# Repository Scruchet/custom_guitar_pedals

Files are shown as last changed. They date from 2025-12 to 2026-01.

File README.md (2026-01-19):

# Custom Guitar Pedals

## Introduction
Since I started learning how to play the electric bass and guitar, and while learning new songs, I discovered effect pedals. They change the sound of the instrument by adding more texture and character. Many different types of pedals exist, and I wanted to understand how they work.

My research is mainly based on a book that I highly recommend: *Electronics for Guitarists* (third edition).

## Project Structure
This repository contains all the files needed to create your own guitar pedals, from electronic design to 3D models and circuit simulation.

The main directory is divided into three subdirectories:
- **mechanical**: Fusion 360 and STEP files for the enclosure
- **pcb**: KiCad projects with an HTML-generated BOM for easier assembly
- **simulation**: LTSpice projects used to design and validate the two main circuits

## Effects
The project currently includes two pedals:
- A clipping pedal
- A fuzz face–style pedal

## Assembly
To assemble the pedals, you will need several components. All passive and active components are listed in the BOM available at `pcb/bom/ibom.html`.

You can 3D print the enclosure, but I do not really recommend it. A pedal needs to be solid and reliable, especially for stage use.  
I bought aluminum enclosures from AliExpress and adapted the designs to fit the available space. The quality is not the best, but this is a DIY project after all.

You will need:
- Two 6.35 mm jack connectors (input and output)
- One DC jack for the power supply
- One LED with its current-limiting resistor
- One 3PDT guitar footswitch

All the components I used are listed in the `components.txt` file.

## Results

`images/result.jpg`

## Project Status

Tested, need pictures for the readme

## License
All hardware designs, schematics, PCB layouts, and mechanical files in this repository
are released under the CERN Open Hardware Licence v2 – Permissive (CERN-OHL-P).

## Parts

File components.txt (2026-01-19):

DC connector : https://fr.aliexpress.com/item/1005010690243937.html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
LED housings : https://fr.aliexpress.com/item/1005010179964783.html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
Pedal Aluminum Box Enclosure : https://fr.aliexpress.com/item/1005006474336072.html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
6.35 mm connectors : https://fr.aliexpress.com/item/1005006144019774.html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
3PDT Guitar Foot Switch : https://fr.aliexpress.com/item/1005009252439906.html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
Potentiometer Knobs : https://fr.aliexpress.com/item/1005009658071171.html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

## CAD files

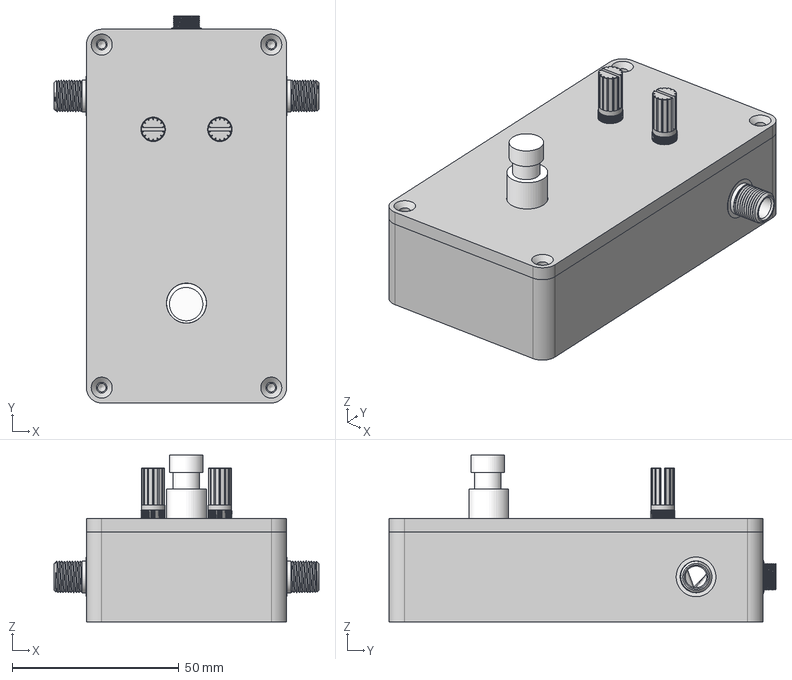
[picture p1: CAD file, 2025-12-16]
mechanical/exports/assembly.step
79.3 x 116.0 x 50.0 mm
PotentiometerB10K x 2
L12B x 2
721A

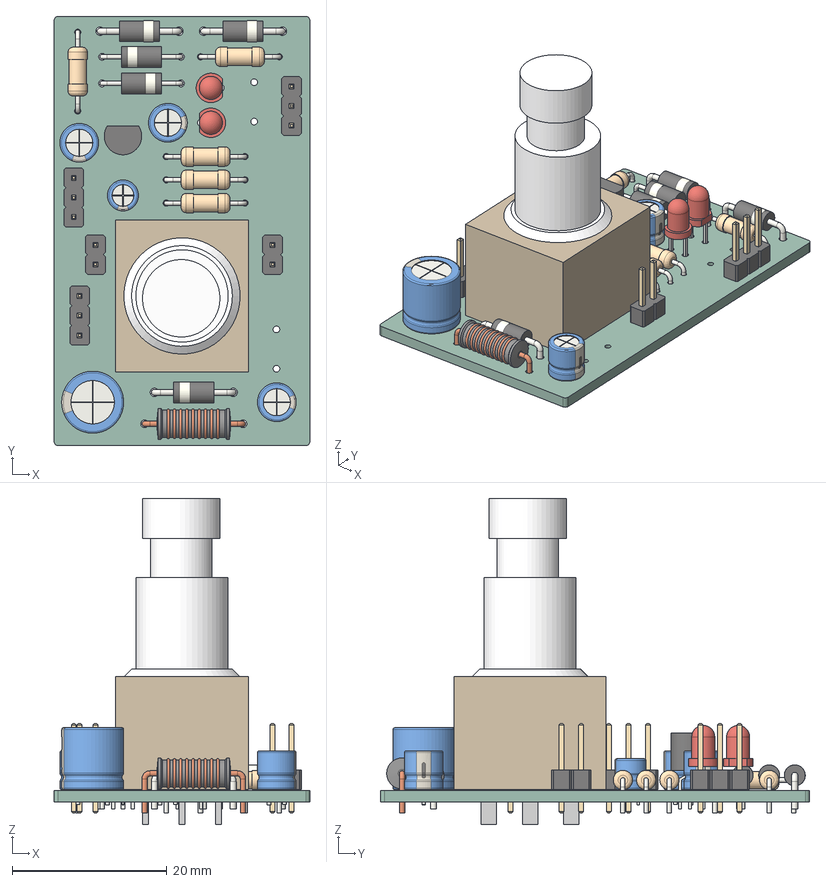
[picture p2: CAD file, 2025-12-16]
mechanical/exports/PCB.step
33.0 x 55.4 x 42.1 mm

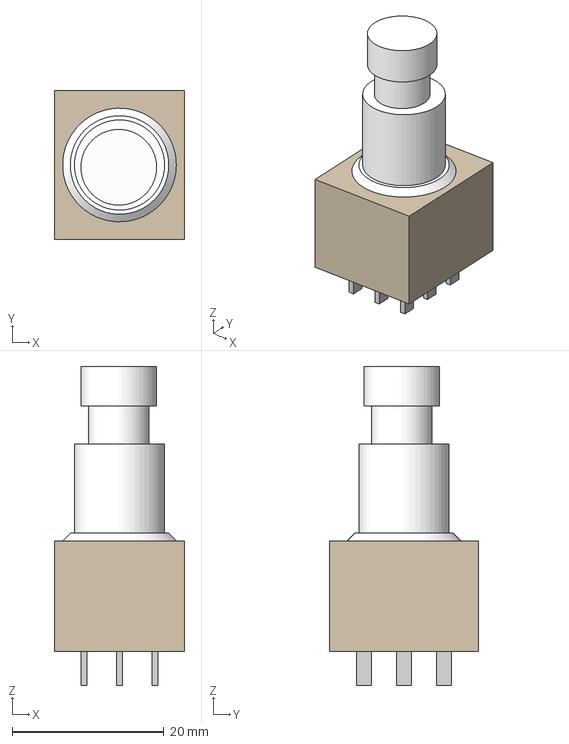
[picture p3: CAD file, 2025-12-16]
pcb/librairies/3d/Switch principal.step
17.2 x 19.6 x 42.1 mm

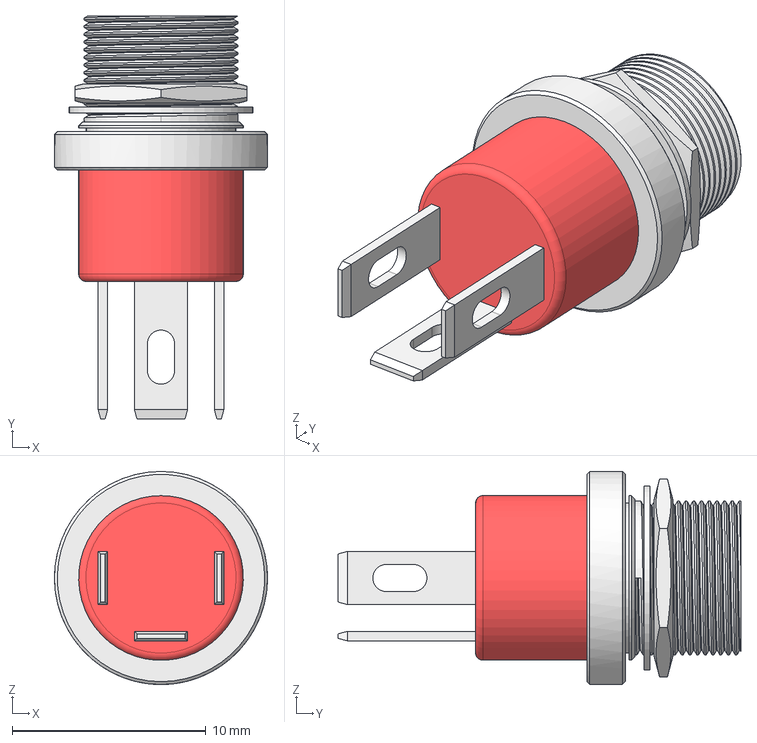
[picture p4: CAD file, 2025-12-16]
mechanical/exports/DC connector.step
11.0 x 20.8 x 11.0 mm

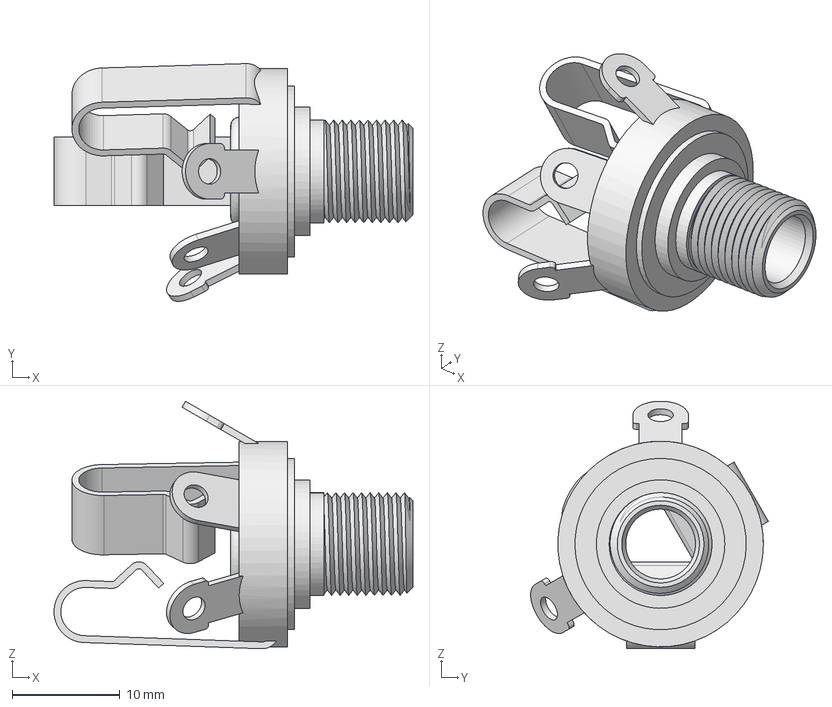
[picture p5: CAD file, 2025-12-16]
mechanical/exports/jack 6.35mm audio.step
33.3 x 22.0 x 22.9 mm

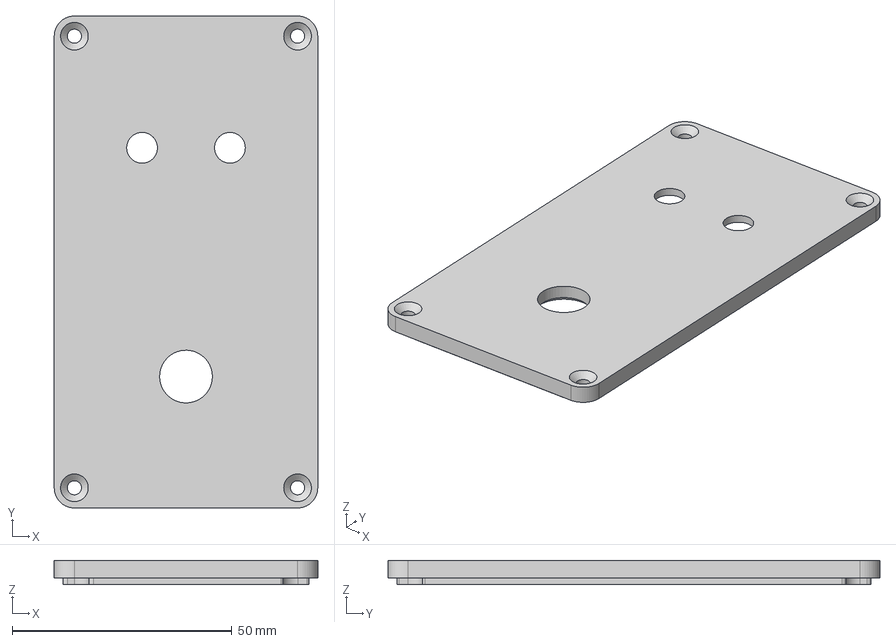
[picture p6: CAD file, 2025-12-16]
mechanical/exports/top_shield.step
60.0 x 112.0 x 5.50 mm

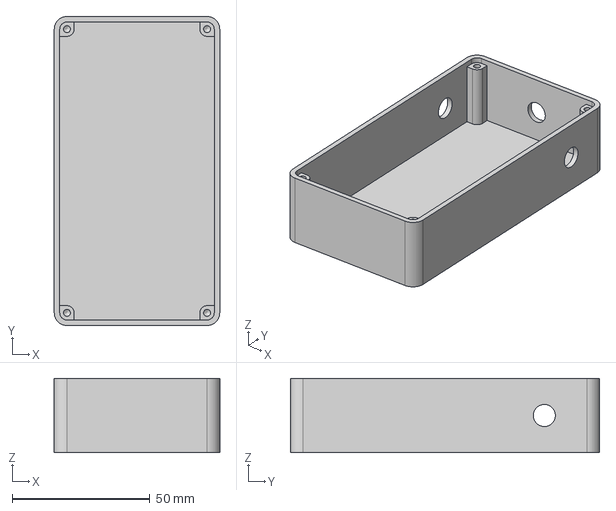
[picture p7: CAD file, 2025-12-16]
mechanical/exports/bottom_shield.step
60.0 x 112.0 x 27.0 mm

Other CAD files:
pcb/pedals.step
mechanical/fusion/DC connector.f3d
mechanical/fusion/PCB.f3d
mechanical/fusion/assembly.f3z
mechanical/fusion/bottom_shield.f3d
mechanical/fusion/jack 6.35mm audio.f3d
mechanical/fusion/top_shield.f3d

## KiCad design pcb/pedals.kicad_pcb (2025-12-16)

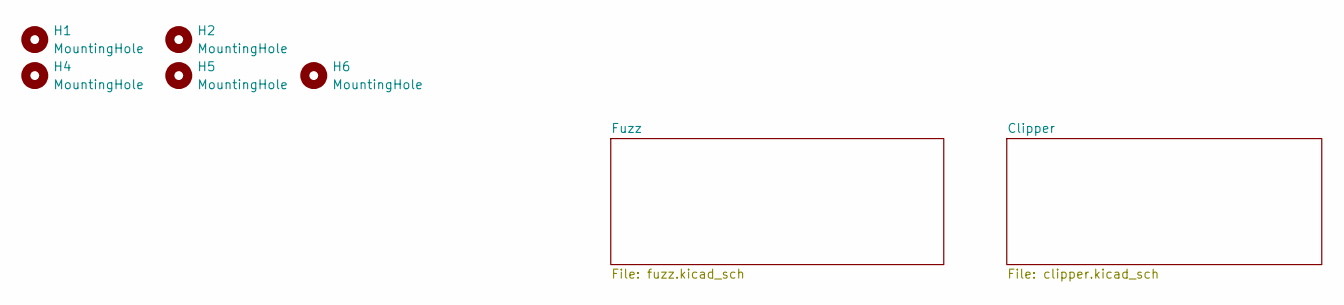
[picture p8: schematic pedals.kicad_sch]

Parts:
H1, H2, H4, H5, H6: MountingHole; mouse-bite-2mm-slot

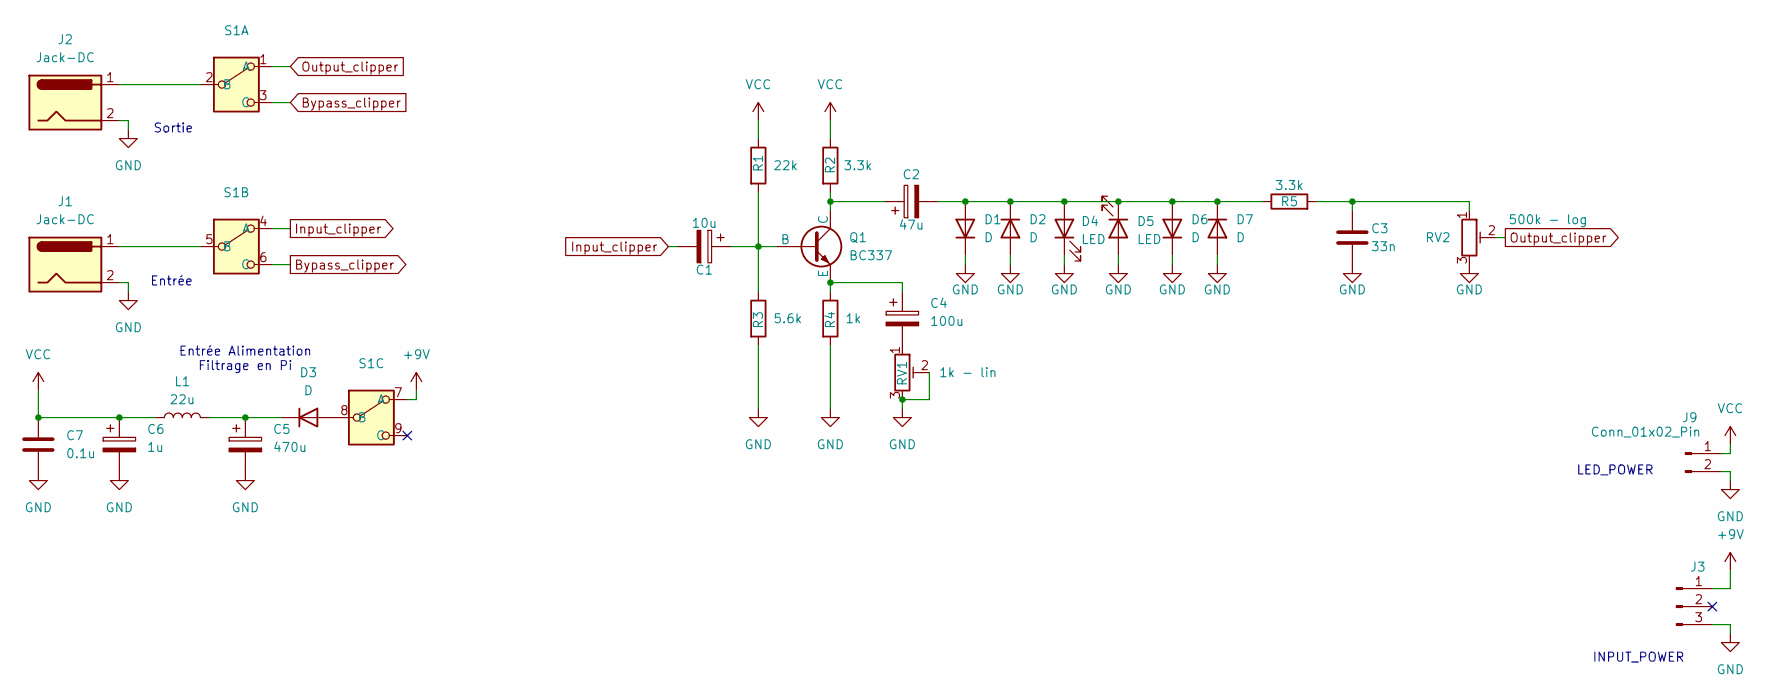
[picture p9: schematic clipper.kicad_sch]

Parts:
C1: 10u; CP_Radial_D4.0mm_P2.00mm
C2: 47u; CP_Radial_D5.0mm_P2.00mm
C3: 33n; CAP_C322_KEM
C4: 100u; CP_Radial_D5.0mm_P2.00mm
C5: 470u; CP_Radial_D8.0mm_P3.80mm
C6: 1u; CP_Radial_D5.0mm_P2.00mm
C7: 0.1u; CAP_C322_KEM
D1, D2, D3: D; D_DO-41_SOD81_P10.16mm_Horizontal
D4, D5: LED; LED_D3.0mm
D6, D7: D; D_A-405_P10.16mm_Horizontal
J1, J2: Jack-DC; PinHeader_1x02_P2.54mm_Vertical
J3: Conn_01x03_Pin; PinHeader_1x03_P2.54mm_Vertical
J9: Conn_01x02_Pin; PinHeader_1x02_P2.54mm_Vertical
L1: 22u; L_Axial_L9.5mm_D4.0mm_P12.70mm_Horizontal_Fastron_SMCC
Q1: BC337; TO-92_HandSolder
R1: 22k; R_Axial_DIN0207_L6.3mm_D2.5mm_P10.16mm_Horizontal
R2, R5: 3.3k; R_Axial_DIN0207_L6.3mm_D2.5mm_P10.16mm_Horizontal
R3: 5.6k; R_Axial_DIN0207_L6.3mm_D2.5mm_P10.16mm_Horizontal
R4: 1k; R_Axial_DIN0207_L6.3mm_D2.5mm_P10.16mm_Horizontal
RV1: 1k - lin; PinHeader_1x03_P2.54mm_Vertical
RV2: 500k - log; PinHeader_1x03_P2.54mm_Vertical
S1: Switch_Principal

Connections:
+9V: J3.1, S1.7 (A)
Bypass_clipper: S1.3 (C), S1.6 (C)
GND: C3.2, C5.2, C6.2, C7.2, D1.1 (K), D2.2 (A), D4.1 (K), D5.2 (A), D6.1 (K), D7.2 (A), J1.2, J2.2, J3.3, J9.2, R3.2, R4.2, RV1.2, RV1.3, RV2.3
Input_clipper: C1.2, S1.4 (A)
unnamed: C3.1, R5.2, RV2.1
unnamed: C4.2, RV1.1
unnamed: C2.2, D1.2 (A), D2.1 (K), D4.2 (A), D5.1 (K), D6.2 (A), D7.1 (K), R5.1
unnamed: D3.2 (A), S1.8 (B)
unnamed: C5.1, D3.1 (K), L1.2
unnamed: C1.1, Q1.2 (B), R1.2, R3.1
unnamed: C2.1, Q1.1 (C), R2.2
unnamed: C4.1, Q1.3 (E), R4.1
unnamed: J2.1, S1.2 (B)
unnamed: J1.1, S1.5 (B)
Output_clipper: RV2.2, S1.1 (A)
VCC: C6.1, C7.1, J9.1, L1.1, R1.1, R2.1

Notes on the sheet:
INPUT_POWER
Entrée Alimentation Filtrage en Pi
Entrée
LED_POWER
Sortie

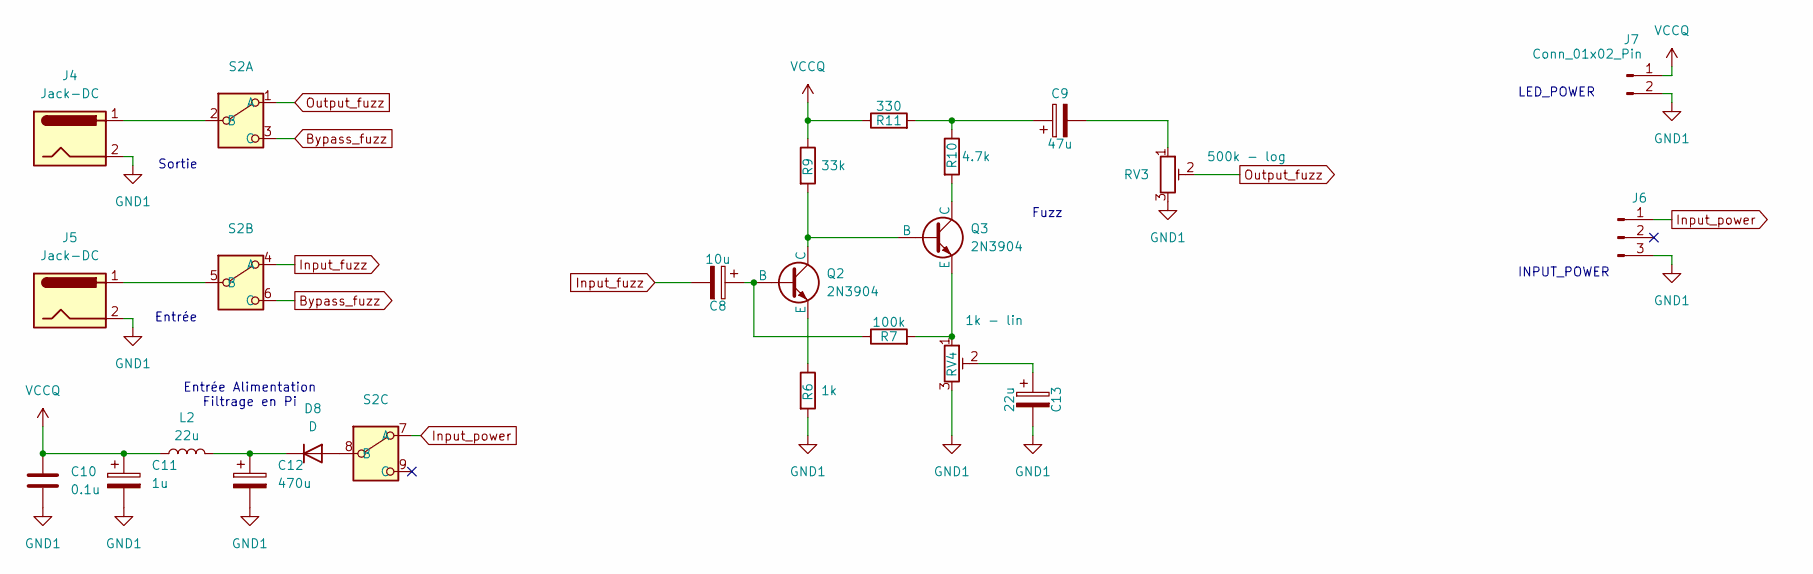
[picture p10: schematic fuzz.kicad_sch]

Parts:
C8: 10u; CP_Radial_D4.0mm_P2.00mm
C9: 47u; CP_Radial_D5.0mm_P2.00mm
C10: 0.1u; CAP_C322_KEM
C11: 1u; CP_Radial_D5.0mm_P2.00mm
C12: 470u; CP_Radial_D8.0mm_P3.80mm
C13: 22u; CP_Radial_D4.0mm_P2.00mm
D8: D; D_DO-41_SOD81_P10.16mm_Horizontal
J4, J5: Jack-DC; PinHeader_1x02_P2.54mm_Vertical
J6: Conn_01x03_Pin; PinHeader_1x03_P2.54mm_Vertical
J7: Conn_01x02_Pin; PinHeader_1x02_P2.54mm_Vertical
L2: 22u; L_Axial_L9.5mm_D4.0mm_P12.70mm_Horizontal_Fastron_SMCC
Q2, Q3: 2N3904
R6: 1k; R_Axial_DIN0207_L6.3mm_D2.5mm_P10.16mm_Horizontal
R7: 100k; R_Axial_DIN0207_L6.3mm_D2.5mm_P10.16mm_Horizontal
R9: 33k; R_Axial_DIN0207_L6.3mm_D2.5mm_P10.16mm_Horizontal
R10: 4.7k; R_Axial_DIN0207_L6.3mm_D2.5mm_P10.16mm_Horizontal
R11: 330; R_Axial_DIN0207_L6.3mm_D2.5mm_P10.16mm_Horizontal
RV3: 500k - log; PinHeader_1x03_P2.54mm_Vertical
RV4: 1k - lin; PinHeader_1x03_P2.54mm_Vertical
S2: Switch_Principal

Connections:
Bypass_fuzz: S2.3 (C), S2.6 (C)
GND1: C10.2, C11.2, C12.2, C13.2, J4.2, J5.2, J6.3, J7.2, R6.2, RV3.3, RV4.3
Input_fuzz: C8.2, S2.4 (A)
Input_power: J6.1, S2.7 (A)
unnamed: C9.1, R10.1, R11.2
unnamed: C9.2, RV3.1
unnamed: C13.1, RV4.2
unnamed: D8.2 (A), S2.8 (B)
unnamed: C12.1, D8.1 (K), L2.2
unnamed: C8.1, Q2.2 (B), R7.1
unnamed: Q2.1 (C), Q3.2 (B), R9.2
unnamed: Q2.3 (E), R6.1
unnamed: Q3.1 (C), R10.2
unnamed: Q3.3 (E), R7.2, RV4.1
unnamed: J4.1, S2.2 (B)
unnamed: J5.1, S2.5 (B)
Output_fuzz: RV3.2, S2.1 (A)
VCCQ: C10.1, C11.1, J7.1, L2.1, R9.1, R11.1

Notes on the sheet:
Sortie
LED_POWER
Fuzz
Entrée Alimentation Filtrage en Pi
Entrée
INPUT_POWER

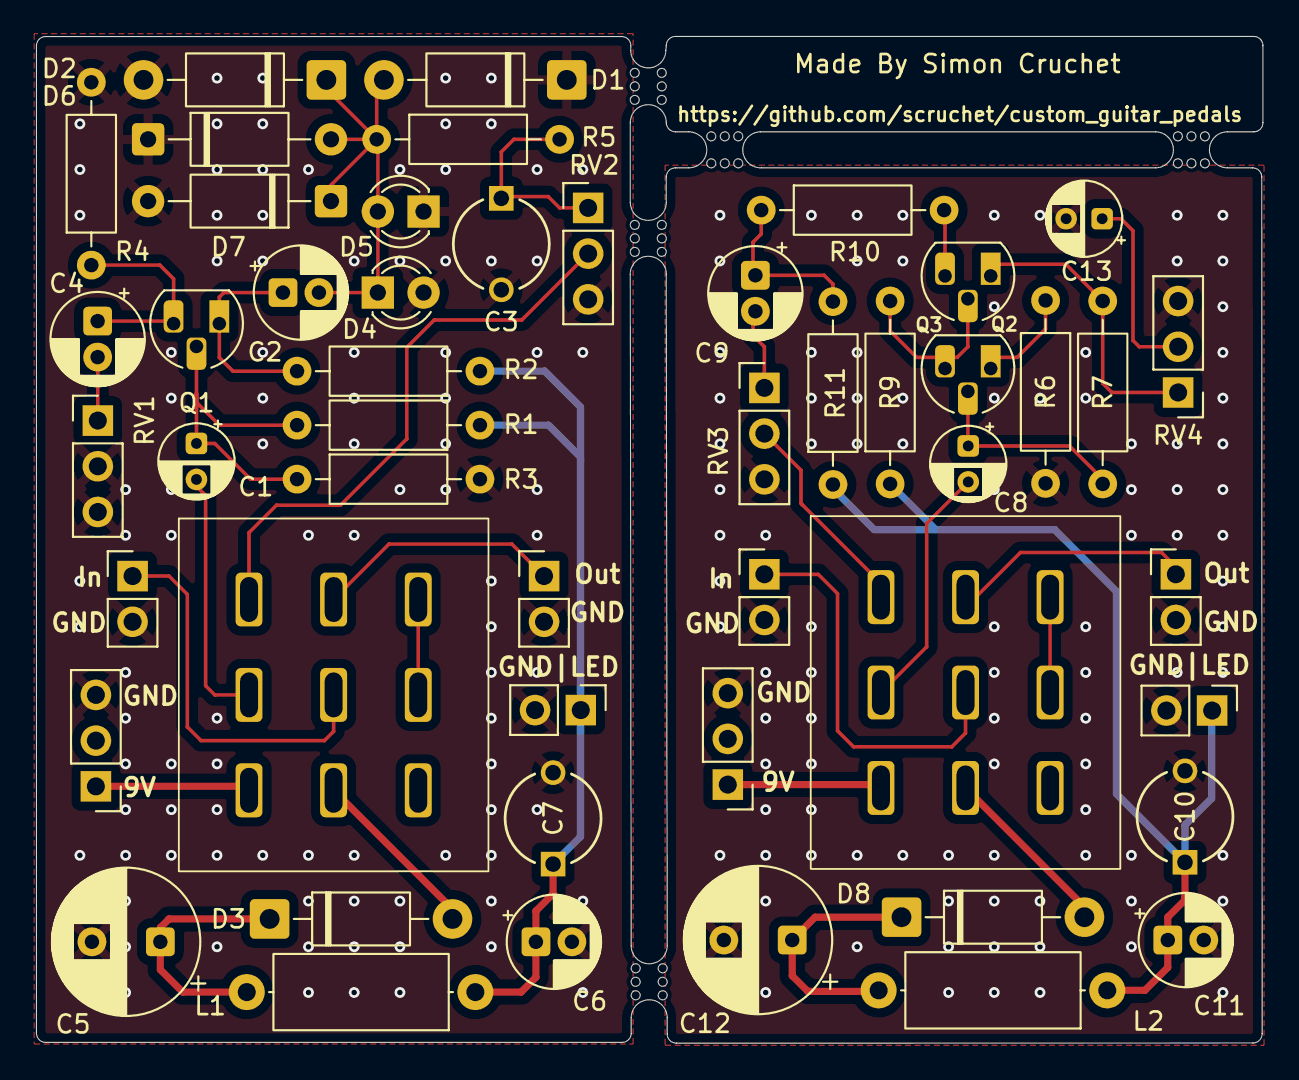
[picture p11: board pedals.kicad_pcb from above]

Board: 2 copper layers, 68.1 x 55.9 mm, 55 parts (0 on the bottom side), 34 nets.

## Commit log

2025-12-16 pcb added; .gitignore added
    [Switch principal.step, clipper.kicad_sch, fuzz.kicad_sch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]
2025-12-16 modification folder name
    [Switch principal.step]
2025-12-16 gerber excluded from git
2025-12-16 adding simulation & mechanical files
    [DC connector.f3d, DC connector.step, PCB.f3d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]
2026-01-19 Enhance README with project details and instructions
    Added detailed project information including structure, effects, assembly instructions, and licensing.
